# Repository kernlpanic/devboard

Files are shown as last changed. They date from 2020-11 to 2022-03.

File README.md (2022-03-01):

# Devboard 

## Description

Just a small devboard with ethernet and rs232 interface.
Almost(tm) fully THD Design with two exceptions. One is the ethernet controller and the other one is the sram module.
The main microcontroller is an Atmega32.
The full BOM I used to build this board will soon be added here

## Disclaimer

This pcb design is still work in progress and not fully testet. 
Still feel free to use it and to contact me if you like to give some advice for improvement

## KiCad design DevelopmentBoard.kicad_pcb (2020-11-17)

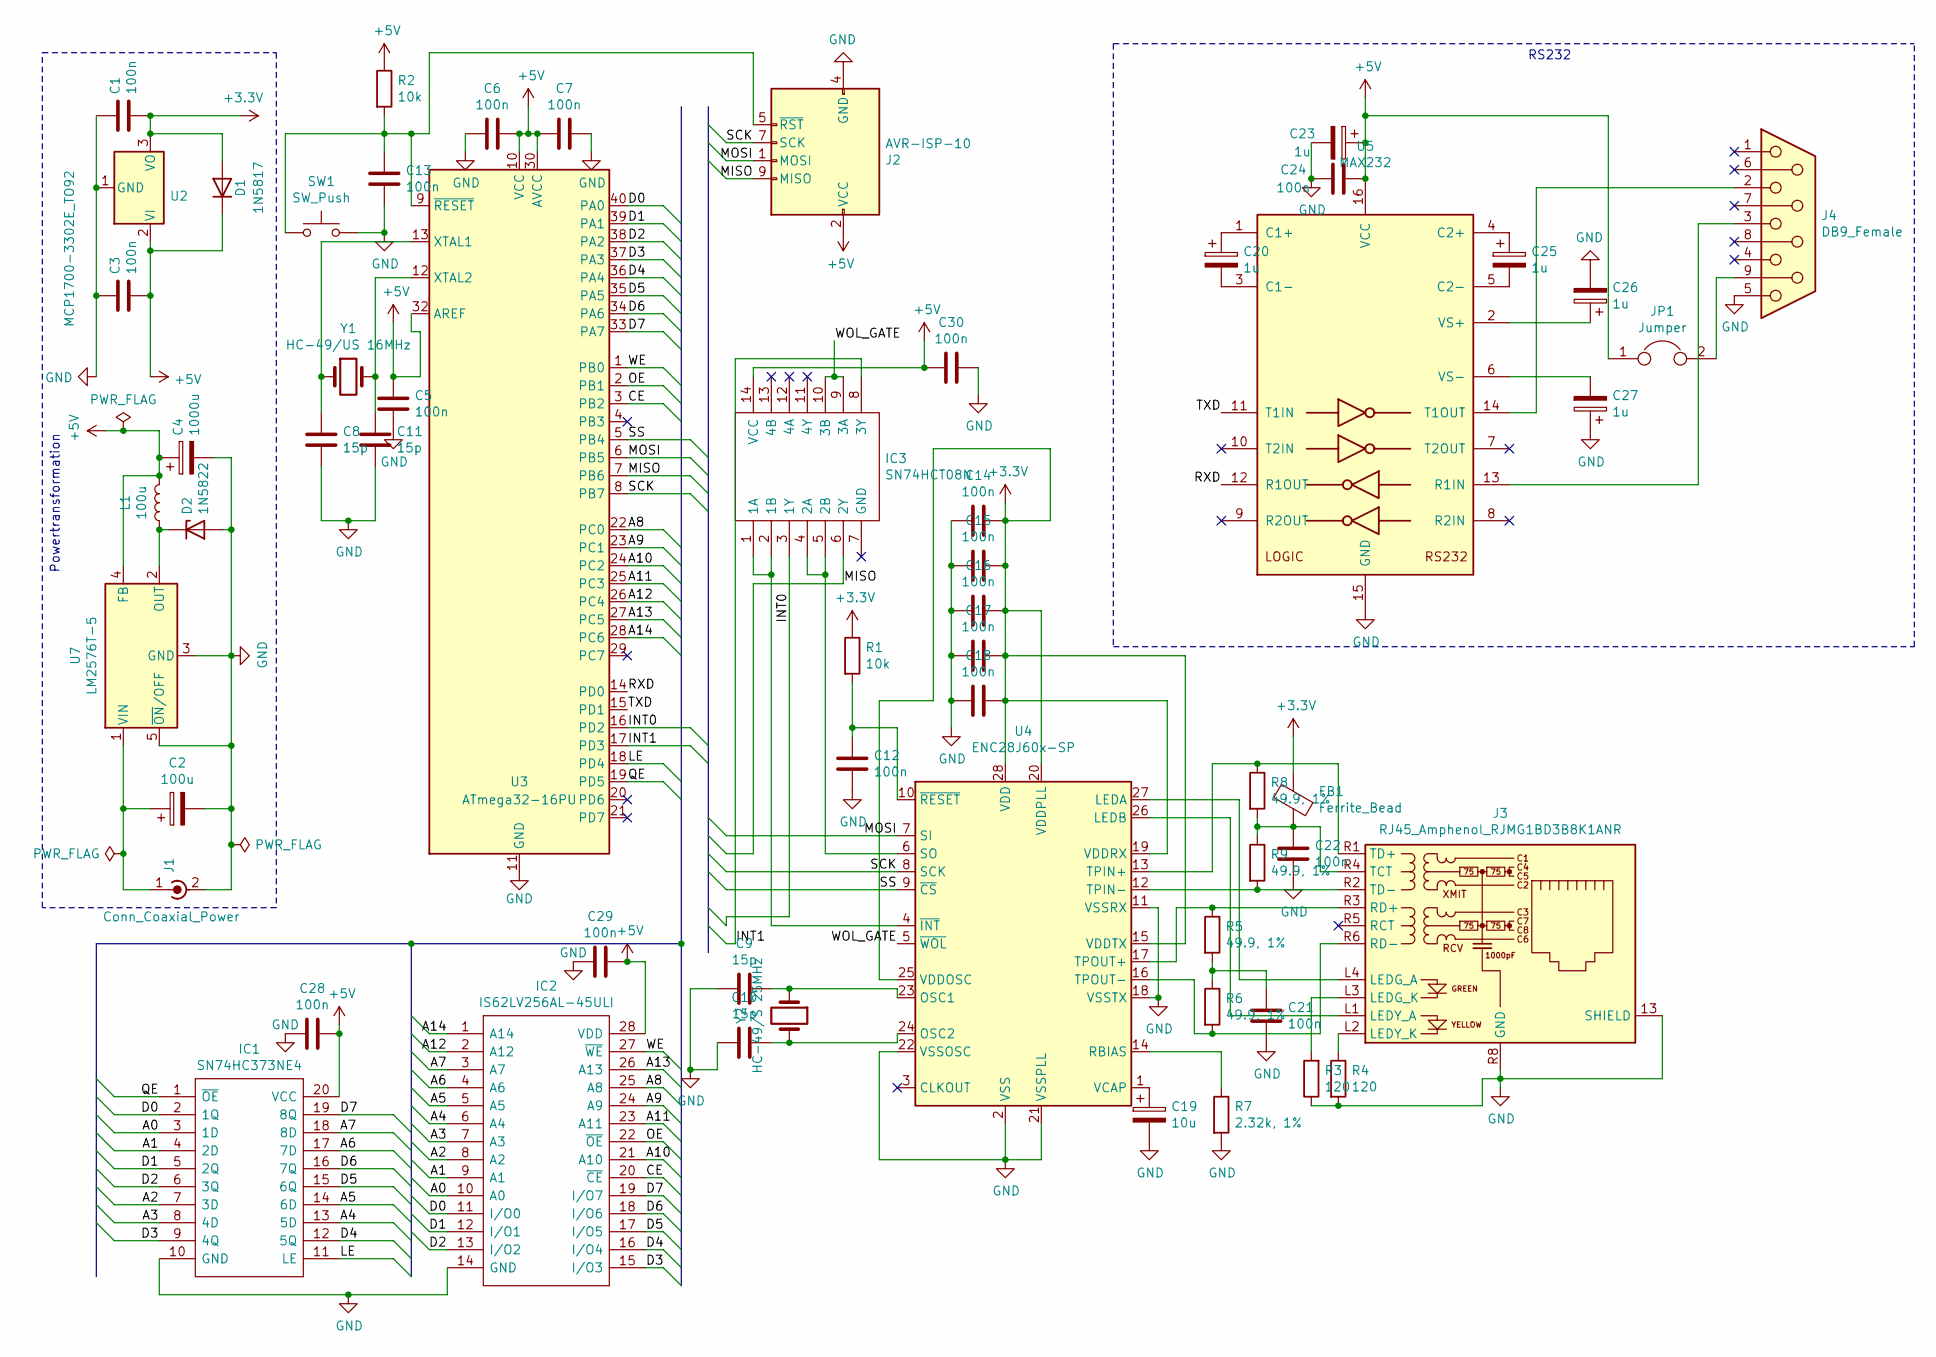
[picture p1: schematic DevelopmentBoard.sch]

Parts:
C1, C3, C5, C6, C7, C12, C13, C14, C15, C16, C17, C18, C21, C22, C24, C28, C29, C30: 100n; C_Disc_D5.0mm_W2.5mm_P5.00mm
C2: 100u; CP_Radial_D8.0mm_P3.50mm
C4: 1000u; CP_Radial_D10.0mm_P5.00mm
C8, C9, C10, C11: 15p; C_Disc_D5.0mm_W2.5mm_P5.00mm
C19: 10u; CP_Radial_D5.0mm_P2.50mm
C20, C23, C25, C26, C27: 1u; CP_Radial_D5.0mm_P2.50mm
D1: 1N5817; D_DO-41_SOD81_P7.62mm_Horizontal
D2: 1N5822; D_DO-201AD_P12.70mm_Horizontal
FB1: Ferrite_Bead; INDAD2070W65L670D350
IC1: SN74HC373NE4; DIP794W53P254L2540H508Q20N; Mouser Part Number 595-SN74HC373NE4
IC2: IS62LV256AL-45ULI; SOIC127P1210X305-28N; Mouser Part Number 870-IS62LV256AL45ULI
IC3: SN74HCT08N; DIP794W53P254L1930H508Q14N; Mouser Part Number 595-SN74HCT08N
J1: Conn_Coaxial_Power; PJ037A
J2: AVR-ISP-10; PinHeader_2x05_P2.54mm_Vertical
J3: RJ45_Amphenol_RJMG1BD3B8K1ANR
J4: DB9_Female; DSUB-9_Female_Horizontal_P2.77x2.84mm_EdgePinOffset7.70mm_H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
JP1: Jumper; PinHeader_1x02_P2.54mm_Vertical
L1: 100u; L_Axial_L7.0mm_D3.3mm_P10.16mm_Horizontal_Fastron_MICC
R1, R2: 10k; R_Axial_DIN0207_L6.3mm_D2.5mm_P10.16mm_Horizontal
R3, R4: 120; R_Axial_DIN0207_L6.3mm_D2.5mm_P15.24mm_Horizontal
R5, R6, R8, R9: 49.9, 1%; R_Axial_DIN0207_L6.3mm_D2.5mm_P10.16mm_Horizontal
R7: 2.32k, 1%; R_Axial_DIN0204_L3.6mm_D1.6mm_P7.62mm_Horizontal
SW1: SW_Push; SW_PUSH_6mm
U2: MCP1700-3302E_TO92; TO-92_Inline_Wide
U3: ATmega32-16PU; DIP-40_W15.24mm_LongPads
U4: ENC28J60x-SP; SOIC-28W_7.5x17.9mm_P1.27mm
U5: MAX232; DIP-16_W7.62mm_LongPads
U7: LM2576T-5; TO-220-5_Vertical
Y1: HC-49/US 16MHz; Crystal_HC49-U_Vertical
Y2: HC-49/S 25MHz; Crystal_HC49-U_Vertical

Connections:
+3V3: C1.2, C14.1, C15.1, C16.1, C17.1, C18.1, D1.2 (A), FB1.2, R1.1, U2.3 (VO), U4.15 (VDDTX), U4.19 (VDDRX), U4.20 (VDDPLL), U4.25 (VDDOSC), U4.28 (VDD)
+5V: C3.2, C4.1, C5.1, C6.1, C7.2, C23.1, C24.1, C28.1, C29.1, C30.2, D1.1 (K), IC1.20 (VCC), IC2.28 (VDD), IC3.14 (VCC), J2.2 (VCC), JP1.1, L1.2, R2.1, U2.2 (VI), U3.10 (VCC), U3.30 (AVCC), U3.32 (AREF), U5.16 (VCC), U7.4 (FB)
/A0: IC1.3 (1D), IC2.10 (A0)
/A1: IC1.4 (2D), IC2.9 (A1)
/A2: IC1.7 (3D), IC2.8 (A2)
/A3: IC1.8 (4D), IC2.7 (A3)
/A4: IC1.13 (5D), IC2.6 (A4)
/A5: IC1.14 (6D), IC2.5 (A5)
/A6: IC1.17 (7D), IC2.4 (A6)
/A7: IC1.18 (8D), IC2.3 (A7)
/A8: IC2.25 (A8), U3.22 (PC0)
/A9: IC2.24 (A9), U3.23 (PC1)
/A10: IC2.21 (A10), U3.24 (PC2)
/A11: IC2.23 (A11), U3.25 (PC3)
/A12: IC2.2 (A12), U3.26 (PC4)
/A13: IC2.26 (A13), U3.27 (PC5)
/A14: IC2.1 (A14), U3.28 (PC6)
/CE: IC2.20 (~CE), U3.3 (PB2)
/D0: IC1.2 (1Q), IC2.11 (I/O0), U3.40 (PA0)
/D1: IC1.5 (2Q), IC2.12 (I/O1), U3.39 (PA1)
/D2: IC1.6 (3Q), IC2.13 (I/O2), U3.38 (PA2)
/D3: IC1.9 (4Q), IC2.15 (I/O3), U3.37 (PA3)
/D4: IC1.12 (5Q), IC2.16 (I/O4), U3.36 (PA4)
/D5: IC1.15 (6Q), IC2.17 (I/O5), U3.35 (PA5)
/D6: IC1.16 (7Q), IC2.18 (I/O6), U3.34 (PA6)
/D7: IC1.19 (8Q), IC2.19 (I/O7), U3.33 (PA7)
/INT0: IC3.3 (1Y), U3.16 (PD2)
/INT1: IC3.8 (3Y), U3.17 (PD3)
/LE: IC1.11 (LE), U3.18 (PD4)
/MISO: IC3.6 (2Y), J2.9 (MISO), U3.7 (PB6)
/MOSI: J2.1 (MOSI), U3.6 (PB5), U4.7 (SI)
/OE: IC2.22 (~OE), U3.2 (PB1)
/QE: IC1.1 (~OE), U3.19 (PD5)
/RXD: U3.14 (PD0), U5.12 (R1OUT)
/SCK: J2.7 (SCK), U3.8 (PB7), U4.8 (SCK)
/SS: U3.5 (PB4), U4.9 (~CS)
/TXD: U3.15 (PD1), U5.11 (T1IN)
/WE: IC2.27 (~WE), U3.1 (PB0)
/WOL_GATE: IC3.9 (3A), IC3.10 (3B), U4.5 (~WOL)
GND: C1.1, C2.2, C3.1, C4.2, C5.2, C6.2, C7.1, C8.2, C9.2, C10.2, C11.2, C12.2, C13.2, C14.2, C15.2, C16.2, C17.2, C18.2, C19.2, C21.2, C22.2, C23.2, C24.2, C26.2, C27.1, C28.2, C29.2, C30.1, D2.2 (A), IC1.10 (GND), IC2.14 (GND), J1.2 (Ext), J2.4 (GND), J2.6 (GND), J2.8 (GND), J2.10 (GND), J3.13 (SHIELD), J3.R8 (GND), J4.5, R3.1, R4.2, R7.2, SW1.2, U2.1 (GND), U3.11 (GND), U3.31 (GND), U4.2 (VSS), U4.11 (VSSRX), U4.18 (VSSTX), U4.21 (VSSPLL), U4.22 (VSSOSC), U5.15 (GND), U7.3 (GND), U7.5 (~ON~/OFF)
unnamed: C2.1, J1.1 (In), U7.1 (VIN)
unnamed: C8.1, U3.13 (XTAL1), Y1.1
unnamed: C9.1, U4.23 (OSC1), Y2.1
unnamed: C10.1, U4.24 (OSC2), Y2.2
unnamed: C11.1, U3.12 (XTAL2), Y1.2
unnamed: C12.1, R1.2, U4.10 (~RESET)
unnamed: C13.1, J2.5 (~RST), R2.2, SW1.1, U3.9 (~RESET)
unnamed: C19.1, U4.1 (VCAP)
unnamed: C20.1, U5.1 (C1+)
unnamed: C20.2, U5.3 (C1-)
unnamed: C21.1, R5.2, R6.1
unnamed: C22.1, FB1.1, J3.R4 (TCT), R8.2, R9.1
unnamed: C25.1, U5.4 (C2+)
unnamed: C25.2, U5.5 (C2-)
unnamed: C26.1, U5.2 (VS+)
unnamed: C27.2, U5.6 (VS-)
unnamed: D2.1 (K), L1.1, U7.2 (OUT)
unnamed: IC3.1 (1A), IC3.2 (1B), U4.4 (~INT)
unnamed: IC3.4 (2A), IC3.5 (2B), U4.6 (SO)
unnamed: J3.L1 (LEDY_A), U4.26 (LEDB)
unnamed: J3.L2 (LEDY_K), R4.1
unnamed: J3.L3 (LEDG_K), R3.2
unnamed: J3.L4 (LEDG_A), U4.27 (LEDA)
unnamed: J3.R1 (TD+), R8.1, U4.13 (TPIN+)
unnamed: J3.R2 (TD-), R9.2, U4.12 (TPIN-)
unnamed: J3.R3 (RD+), R5.1, U4.17 (TPOUT+)
unnamed: J3.R6 (RD-), R6.2, U4.16 (TPOUT-)
unnamed: J4.2, U5.14 (T1OUT)
unnamed: J4.3, U5.13 (R1IN)
unnamed: J4.9, JP1.2
unnamed: R7.1, U4.14 (RBIAS)

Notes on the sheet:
RS232
Powertransformation

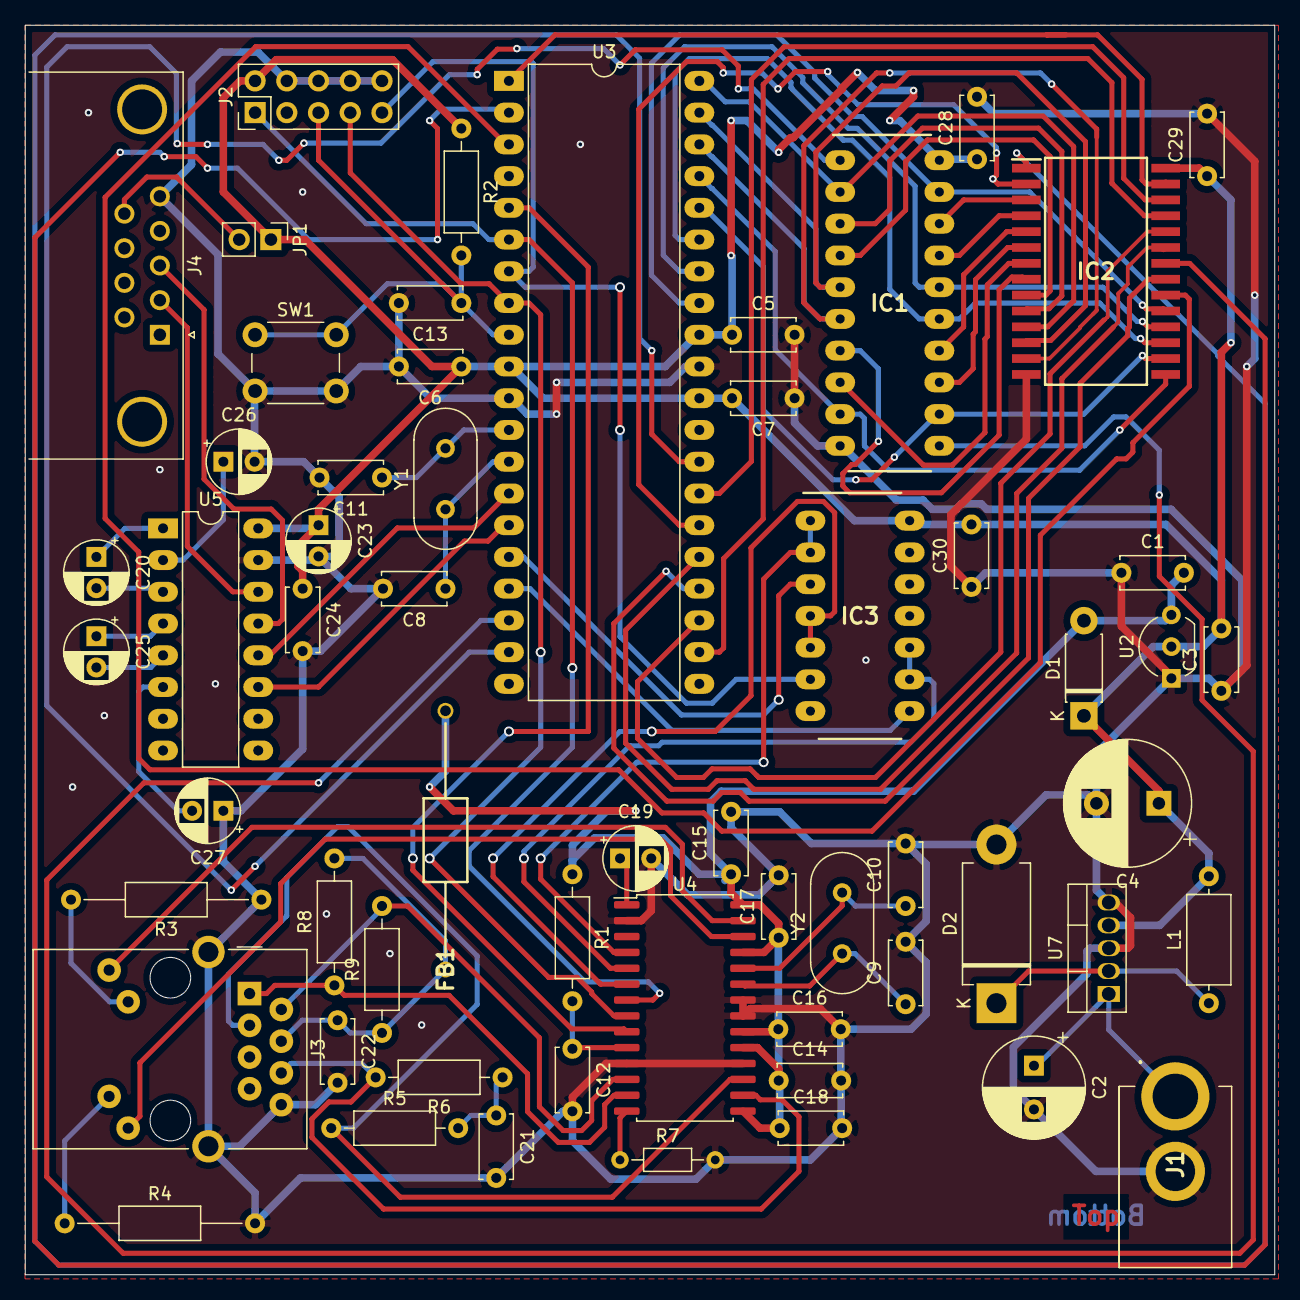
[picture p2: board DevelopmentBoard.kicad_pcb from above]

Board: 2 copper layers, 100.0 x 100.0 mm, 59 parts (0 on the bottom side), 71 nets.

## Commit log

2020-10-30 init commit
    [DevelopementBoard.kicad_pcb, DevelopementBoard.sch]
2020-10-30 update board
    [DevelopementBoard.sch]
2020-11-09 add ethernet to board
    [DevelopementBoard.sch]
2020-11-10 rearrange symbols
    [DevelopementBoard.sch]
2020-11-12 finish first version of board
    [DevelopementBoard.sch]
2020-11-14 add most footprints to schematics
    [DevelopementBoard.sch]
2020-11-15 add missing footprints
    [DevelopementBoard.kicad_pcb, DevelopementBoard.sch]
2020-11-15 place initial layout
    [DevelopementBoard.kicad_pcb, DevelopementBoard.sch]
2020-11-16 fix pad clearance problems
    [DevelopementBoard.kicad_pcb, DevelopementBoard.sch]
2020-11-17 connect most parts
    [DevelopementBoard.kicad_pcb]
2020-11-17 draw all connections
    [DevelopementBoard.kicad_pcb]
2020-11-17 fix layout and draw gnd planes
    [DevelopementBoard.kicad_pcb]
2020-11-17 finish pcb design
    [DevelopementBoard.kicad_pcb]
2020-11-17 add title to board
    [DevelopementBoard.kicad_pcb]
2020-11-17 add some vias for the gnd plane
    [DevelopementBoard.kicad_pcb]
2020-11-17 add 3D objects to footprints
    [DevelopementBoard.kicad_pcb]
2022-03-01 rename project
    [DevelopmentBoard.kicad_pcb, DevelopmentBoard.sch]
